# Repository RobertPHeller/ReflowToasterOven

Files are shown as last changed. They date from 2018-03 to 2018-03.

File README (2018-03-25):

This project is based on the Instructables "Hack a Toaster Oven for Reflow
Soldering" by frank26080115 at
https://www.instructables.com/id/Hack-a-Toaster-Oven-for-Reflow-Soldering/

Notable differences:

1) It uses an ArduinoUno as the processing element and all of the electronics 
(except the display, pushbuttons, buzzer, and relay) are mounted on an 
Adafruit Proto Shield -- all of the components are through-hole components.

There is a KiCAD project here. It includes a "four layer" board. Actually I
have no intention of creating a "four layer" PCB. I intend to build this on an
Adafruit protoshield (Product #2077). The PCB I "designed" with KiCAD is a
mock up for the Adafruit protoshield (almost). The red and green layers
represent the wiring already on the protoshield, and includes the bus strips.
The blue and white "layers" represent the added wiring. The board also
provides the approximate component placement. For those people without KiCAD
installed, I have included a PDF of the schematic in the file
ReflowToasterOven.pdf and some "pictures" of the board in the BoardPictures
folder (one is a screen shot of the KiCAD PCB layout and the others are from
the 3D viewer).

2) Everything is mounted in a pair of plastic boxes and instead of "hacking"
an extension code, an AC power entry module and a pair of AC Receptacles are
used.

There are three files related to the mechanical construction:

ReflowToasterOven-mech.tcl
ReflowToasterOven-mech.gcad
ReflowToasterOven-mech.dxf

ReflowToasterOven-mech.tcl is a Tcl program that generates the 
ReflowToasterOven-mech.gcad file, which is the input for the GCAD3D program.  
The ReflowToasterOven-mech.dxf is a DXF file, that can be imported to any 3D 
cad program.

3) An Adafruit 1.8" *Color* TFT LCD SPI display is used, using Adafruit's 
graphics library.

4) The software is a "standard" Arduino project.

And the code lives in the ReflowToasterOven subdirectory. It compiles
successfully and just fits in the Uno's flash memory and only 1/2 of the SRAM
is used by static variables, leaving just under 1K for dynamic variables.

You will need to install the Adafruit ST7735 and Adafruit_GFX libraries from 
Adafruit's GitHub repo.  You will also need the MsTimer2 library 
(http://www.pjrc.com/teensy/td_libs_MsTimer2.html).

*Most* of the code is copied from the original program by frank26080115.  I 
modified things to use C++ classes and adapted to use the Arduino I/O 
libraries, the Adafruit ST7735-based TFT display and the MsTimer2 library.

I have not built or tested it yet.

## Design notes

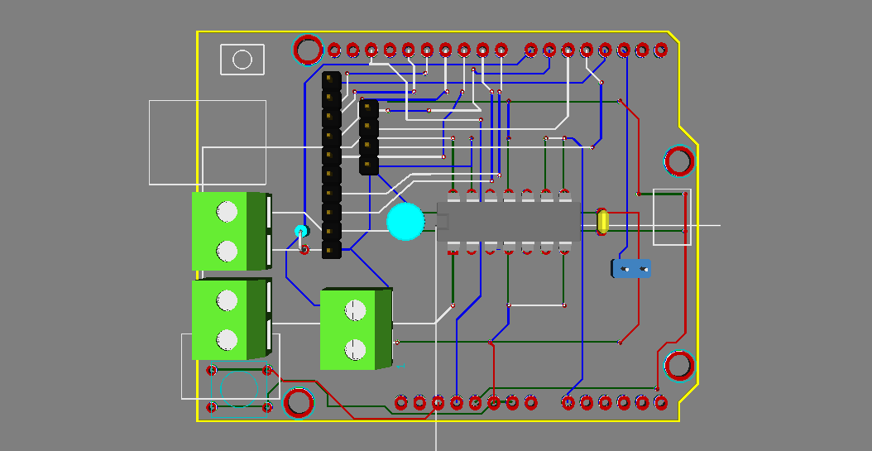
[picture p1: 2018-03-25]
BoardPictures/ReflowToasterOven_Top3D.png

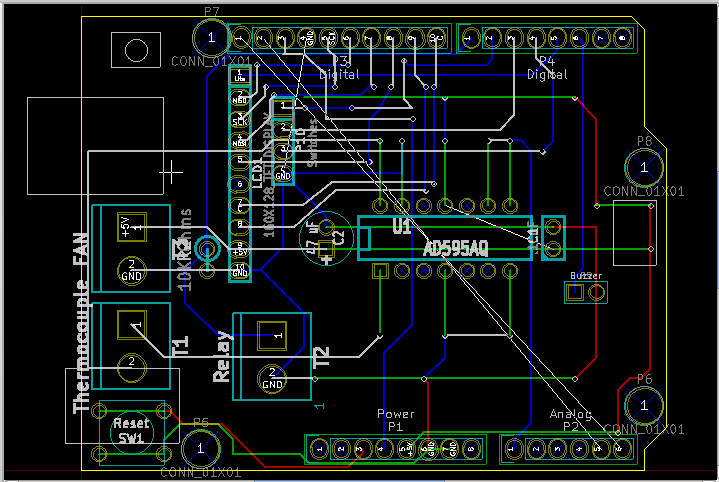
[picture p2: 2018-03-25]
BoardPictures/FabImage.png

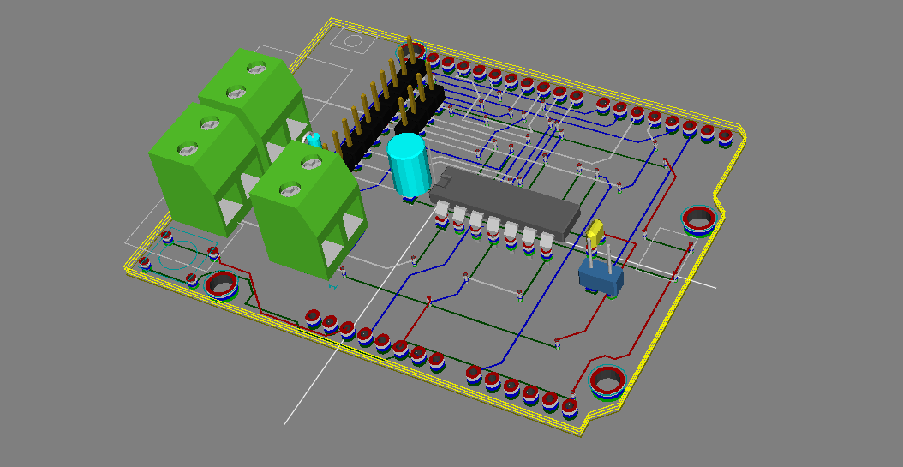
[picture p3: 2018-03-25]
BoardPictures/ReflowToasterOven_Axo3D.png

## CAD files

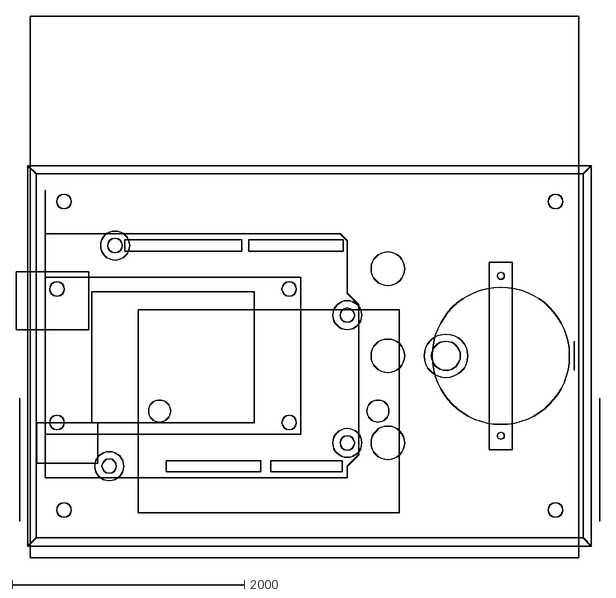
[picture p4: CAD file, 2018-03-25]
ReflowToasterOven-mech.dxf
5023.6 x 4664.1

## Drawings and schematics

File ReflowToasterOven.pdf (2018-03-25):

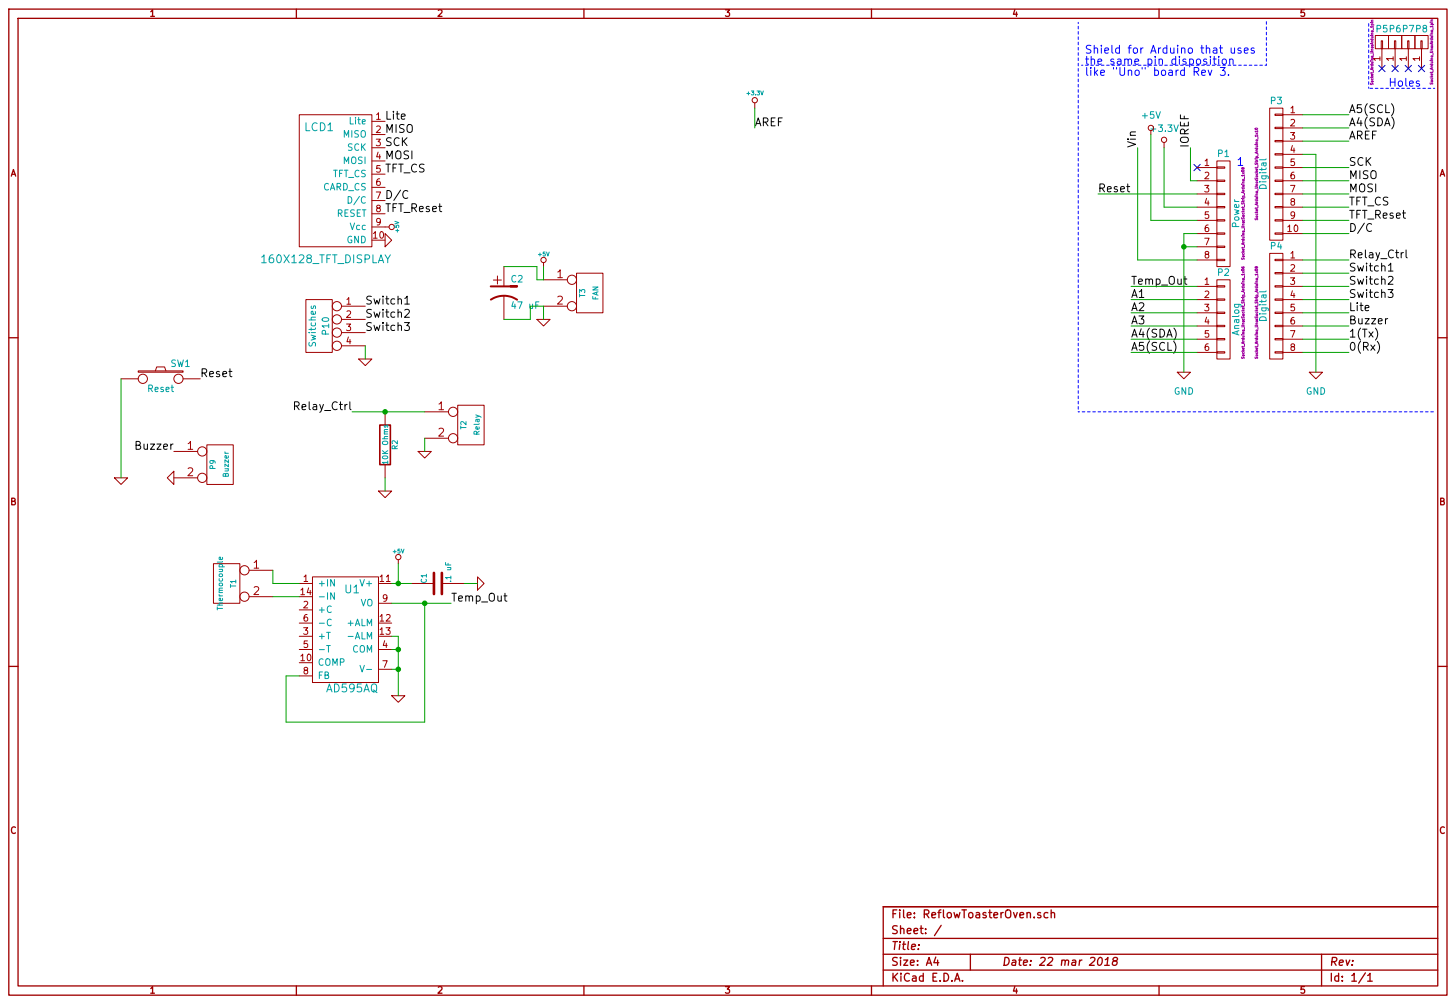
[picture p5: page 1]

A5(SCL)Holes Shield for Arduino that uses
the same pin disposition
like "Uno" board Rev 3. 1

Id: 1/1 Title: File: ReflowToasterOven.sch

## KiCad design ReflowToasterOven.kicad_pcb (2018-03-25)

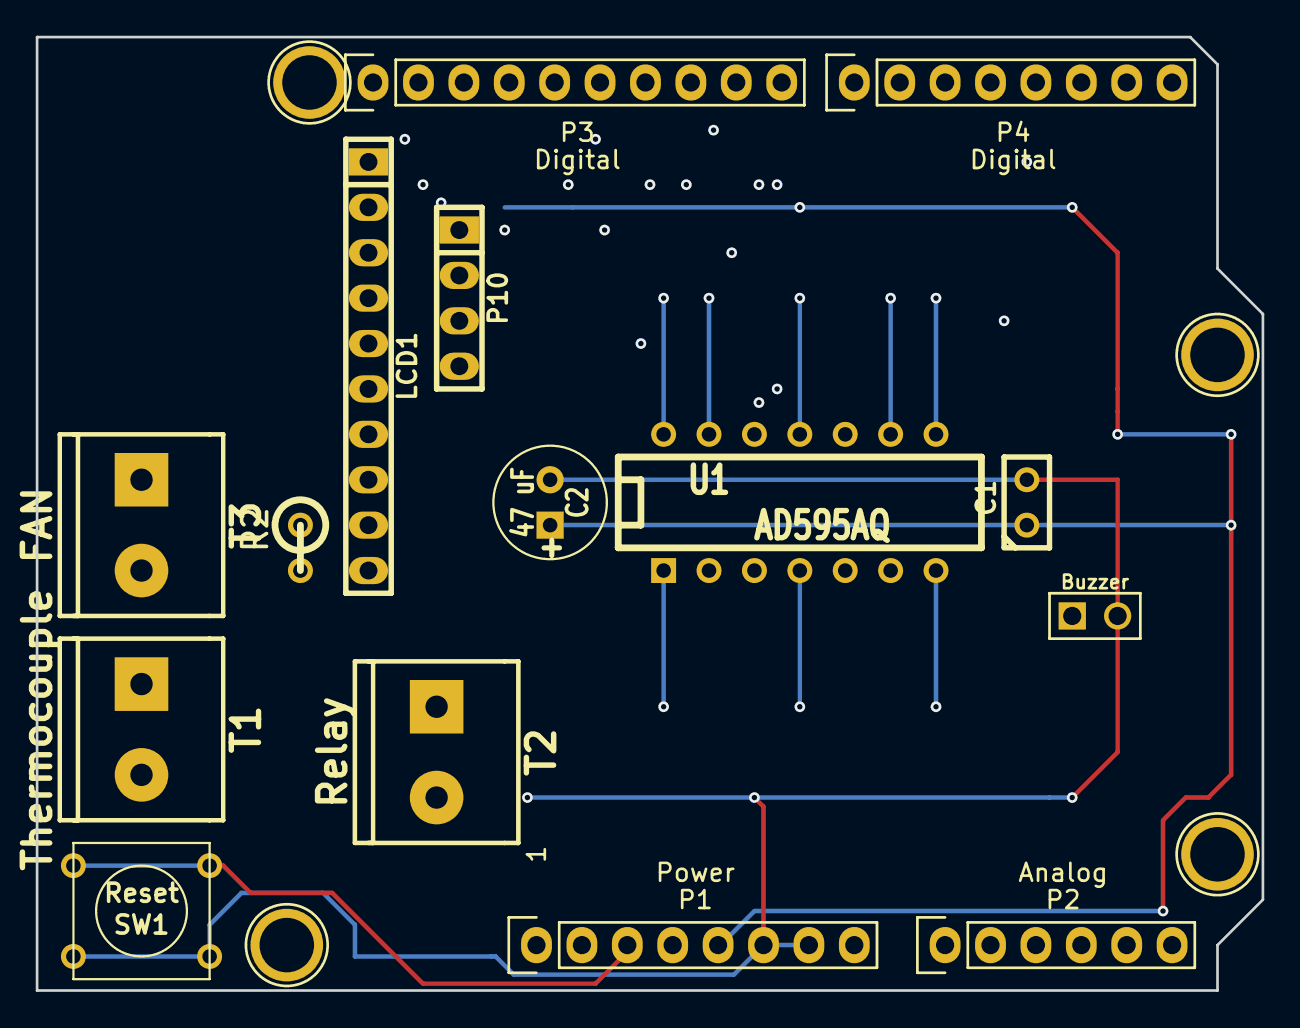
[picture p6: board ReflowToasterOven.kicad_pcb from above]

Board: 4 copper layers, 68.6 x 53.3 mm, 19 parts (0 on the bottom side), 21 nets.

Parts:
C1: .1 uF; C1
C2: 47 uF; C1V7
LCD1: 160X128_TFT_DISPLAY; pin_strip_10
P1: Power; Socket_Strip_Arduino_1x08
P2: Analog; Socket_Strip_Arduino_1x06
P3: Digital; Socket_Strip_Arduino_1x10
P4: Digital; Socket_Strip_Arduino_1x08
P5, P6, P7, P8: CONN_01X01; Arduino_1pin
P9: Buzzer; PIN_ARRAY_2X1
P10: Switches; pin_strip_4
R2: 10K Ohms; R1
SW1: Reset; SW_PUSH_SMALL
T1: Thermocouple; mors_2p
T2: Relay; mors_2p
T3: FAN; mors_2p
U1: AD595AQ; DIP-14__300

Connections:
+3.3V: P1.4, P3.3
+5V: C1.1, C2.1, LCD1.9, P1.5, T3.1, U1.11
/A4(SDA): P2.5, P3.2
/A5(SCL): P2.6, P3.1
/Buzzer: P4.6, P9.1
/D/C: LCD1.7, P3.10
/Lite: LCD1.1, P4.5
/MISO: LCD1.2, P3.6
/MOSI: LCD1.4, P3.7
/Relay_Ctrl: P4.1, R2.1, T2.1
/Reset: P1.3, SW1.2
/SCK: LCD1.3, P3.5
/Switch1: P4.2, P10.1
/Switch2: P4.3, P10.2
/Switch3: P4.4, P10.3
/TFT_CS: LCD1.5, P3.8
/TFT_Reset: LCD1.8, P3.9
/Temp_Out: P2.1, U1.8, U1.9
GND: C1.2, C2.2, LCD1.10, P1.6, P1.7, P3.4, P9.2, P10.4, R2.2, SW1.1, T2.2, T3.2, U1.4, U1.7, U1.13
unnamed: T1.1, U1.1
unnamed: T1.2, U1.14

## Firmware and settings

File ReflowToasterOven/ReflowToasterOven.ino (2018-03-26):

// -!- C++ -!- //////////////////////////////////////////////////////////////
//
//  System        : 
//  Module        : 
//  Object Name   : $RCSfile$
//  Revision      : $Revision$
//  Date          : $Date$
//  Author        : $Author$
//  Created By    : Robert Heller
//  Created       : Sat Mar 24 13:01:57 2018
//  Last Modified : <180326.1323>
//
//  Description	
//
//  Notes
//
//  History
//	
/////////////////////////////////////////////////////////////////////////////
//
//    
//    Copyright (C) 2018  Robert Heller D/B/A Deepwoods Software
//    (Portions Copyright (C) 2011 Frank Zhao)
//			51 Locke Hill Road
//			Wendell, MA 01379-9728
//
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
// 
//
//////////////////////////////////////////////////////////////////////////////
#include <Arduino.h>
#include <stdio.h>
#include <MsTimer2.h>
#include <EEPROM.h>
#include <Adafruit_GFX.h>
#include <Adafruit_ST7735.h>
#include <SPI.h>
#include "reflowtoasteroven.h"
#include "temperaturemeasurement.h"
#include "heatingelement.h"
#include "Menu.h"

static const char rcsid[] PROGMEM = "@(#) : $Id$";

settings_t settings; // store this globally so it's easy to access

void tmr_init();

Menu menu = Menu();
TemperatureMeasurement sensor = TemperatureMeasurement();
Heat element = Heat();

void setup()
{
    Serial.begin(115200);
    Serial.println(PSTR("Initializing..."));
    
    sensor.init();
    element.init();
    tmr_init();
    menu.init();
    Serial.println(PSTR("Reflow Toaster Oven 1.0 Setup finished"));
    menu.main();
}

void loop() {} // Not used

volatile uint16_t tmr_ovf_cnt = 0;
volatile char tmr_checktemp_flag = 0;
volatile char tmr_drawlcd_flag = 0;
volatile char tmr_writelog_flag = 0;

void TIMER0_OVF_vect()
{
    element.isr();
    sensor.get_ADC_sample();
    
    tmr_ovf_cnt++;
    if (tmr_ovf_cnt % 1024 == 0) // about 2s
    {
        tmr_ovf_cnt = 0;
        tmr_checktemp_flag = 1;
        tmr_drawlcd_flag = 1;
        tmr_writelog_flag = 1;
    }
    else if (tmr_ovf_cnt % 512 == 0) // about 1s
    {
        tmr_checktemp_flag = 1;
        tmr_writelog_flag = 1;
    }
    else if (tmr_ovf_cnt % 256 == 0) // about 0.5s
    {
        tmr_checktemp_flag = 1;
    }
}

void tmr_init()
{
    MsTimer2::set(2, TIMER0_OVF_vect);
    MsTimer2::start();
}

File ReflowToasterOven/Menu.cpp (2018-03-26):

// -!- C++ -!- //////////////////////////////////////////////////////////////
//
//  System        : 
//  Module        : 
//  Object Name   : $RCSfile$
//  Revision      : $Revision$
//  Date          : $Date$
//  Author        : $Author$
//  Created By    : Robert Heller
//  Created       : Sat Mar 24 14:46:53 2018
//  Last Modified : <180326.1321>
//
//  Description	
//
//  Notes
//
//  History
//	
/////////////////////////////////////////////////////////////////////////////
//
//    Copyright (C) 2018  Robert Heller D/B/A Deepwoods Software
//    (Portions Copyright (C) 2011 Frank Zhao)
//			51 Locke Hill Road
//			Wendell, MA 01379-9728
//
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
// 
//
//////////////////////////////////////////////////////////////////////////////


#include <Arduino.h>
#include "reflowtoasteroven.h"
#include "Menu.h"
#include "pitches.h"
static const char rcsid[] PROGMEM = "@(#) : $Id$";



// this estimates the PWM duty cycle needed to reach a certain steady temperature
// if the toaster is capable of a maximum of 300 degrees, then 100% duty cycle is used if the target temperature is 300 degrees, and 0% duty cycle is used if the target temperature is room temperature.
double Menu::approx_pwm(double target)
{
    return 65535.0 * ((target * THERMOCOUPLE_CONSTANT) / settings.max_temp);
}

uint16_t Menu::pid(double target, double current, double * integral, double * last_error)
{
    double error = target - current;
    if (target == 0)
    {
        // turn off if target temperature is 0
        
        (*integral) = 0;
        (*last_error) = error;
        return 0;
    }
    else
    {
        if (target < 0)
        {
            target = 0;
        }
        
        // calculate PID terms
        
        double p_term = settings.pid_p * error;		
        double new_integral = (*integral) + error;
        double d_term = ((*last_error) - error) * settings.pid_d;
        (*last_error) = error;
        double i_term = new_integral * settings.pid_i;
        
        double result = approx_pwm(target) + p_term + i_term + d_term;
        
        // limit the integral so it doesn't get out of control
        if ((result >= 65535.0 && new_integral < (*integral)) || (result < 0.0 && new_integral > (*integral)) || (result <= 65535.0 && result >= 0))
        {
            (*integral) = new_integral;
        }
        
        // limit the range and return the rounded result for use as the PWM OCR value
        return (uint16_t)lround(result > 65535.0 ? 65535.0 : (result < 0.0 ? 0.0 : result));
    }
}

// changes a value based on the up and down buttons
double Menu::button_change_double(double oldvalue, double increment, double limit1, double limit2)
{
	double maxlimit = limit1 >= limit2 ? limit1 : limit2;
	double minlimit = limit1 < limit2 ? limit1 : limit2;
	
	if (button_up())
	{
		button_debounce();

		// the amount of change occurs increases as the button is held down for longer
		button_held = (button_held < 200) ? (button_held + 1) : button_held;
		increment += increment*(button_held/3);

		// return the changed value
		return ((oldvalue + increment) > maxlimit) ? maxlimit : (oldvalue + increment);
		// the range of this value is also limited
	}
	else if (button_down())
	{
		button_debounce();

		// the amount of change occurs increases as the button is held down for longer
		button_held = (button_held < 200) ? (button_held + 1) : button_held;
		increment += increment*(button_held/3);

		// return the changed value
		return ((oldvalue - increment) < minlimit) ? minlimit : (oldvalue - increment);
		// the range of this value is also limited
	}
	else
	{
		// no button pressed, meaning button is not held down
		button_held = 0;
		// and the value does not change, but keep it in range
		return (oldvalue > maxlimit) ? maxlimit : ((oldvalue < minlimit) ? minlimit : oldvalue);
	}
}

// same as above but for integers
int32_t Menu::button_change_int(int32_t oldvalue, int32_t increment, int32_t limit1, int32_t limit2)
{
	int32_t maxlimit = limit1 >= limit2 ? limit1 : limit2;
	int32_t minlimit = limit1 < limit2 ? limit1 : limit2;
	
	if (button_up())
	{
		button_debounce();

		// the amount of change occurs increases as the button is held down for longer
		button_held = (button_held < 100) ? (button_held + 1) : button_held;
		increment += increment*(button_held/3);

		// return the changed value
		return ((oldvalue + increment) > maxlimit) ? maxlimit : (oldvalue + increment);
		// the range of this value is also limited
	}
	else if (button_down())
	{
		button_debounce();

		// the amount of change occurs increases as the button is held down for longer
		button_held = (button_held < 100) ? (button_held + 1) : button_held;
		increment += increment*(button_held/3);

		// return the changed value
		return ((oldvalue - increment) < minlimit) ? minlimit : (oldvalue - increment);
		// the range of this value is also limited
	}
	else
	{
		// no button pressed, meaning button is not held down
		button_held = 0;
		// and the value does not change, but keep it in range
		return (oldvalue > maxlimit) ? maxlimit : ((oldvalue < minlimit) ? minlimit : oldvalue);
	}
}

char* Menu::str_from_double(double value, int decimalplaces)
{
	char* result = dtostrf(value, -(LCD_WIDTH/FONT_WIDTH), decimalplaces, strbuf);
	
	// trim trailing spaces
	int8_t len = strlen(result);
	len--;
	while (result[len] == ' ' && len >= 0)
	{
		result[len] = 0;
		len--;
	}
	return result;
}
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

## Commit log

2018-03-25 Release 0.0
    [ReflowToasterOven.csv, ReflowToasterOven.kicad_pcb, ReflowToasterOven.sch]
2018-03-25 Update mechanical drawings.
    [ReflowToasterOven-mech.dxf]
2018-03-25 Items missing from parts list, minor fix to PC board.
    [ReflowToasterOven.kicad_pcb]
2018-03-25 PDF of Schematic, images of the circuitboard.
2018-03-25 Minor tweaks to the firmware: programable colors, added in buzzer, removed unneeded include.
    [Menu.cpp, Menu.h, ReflowToasterOven.ino]
2018-03-26 Code tweaks: embed the temp sensor and heating element in proper C++ classes and eleminate almost all of the loose global variables.
    [Menu.cpp, Menu.h, ReflowToasterOven.ino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]

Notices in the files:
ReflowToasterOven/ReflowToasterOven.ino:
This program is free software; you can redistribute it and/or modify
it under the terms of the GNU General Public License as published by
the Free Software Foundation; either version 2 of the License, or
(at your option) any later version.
